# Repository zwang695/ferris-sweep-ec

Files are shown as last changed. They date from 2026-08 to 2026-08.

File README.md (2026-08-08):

# Ferris Sweep EC

An open, 34-key (`3x5+2` per half) Topre electrocapacitive split keyboard using
Ferris Sweep-style geometry and the known-built Tako Rev1 sensing architecture.

## Tooling

KiCad 10.0.5 is installed through Flatpak. Use `./scripts/kicad-cli` for
schematic ERC, PCB DRC, exports, and renders. QMK CLI 1.2.0 is also available;
firmware is kept reproducible in this repository rather than depending on the
machine's existing QMK checkout.

This repository is an engineering project. Files under `production/` are not
released for fabrication until every check in `docs/verification-plan.md` has
passed and the release is explicitly tagged as a prototype.

## Revision A goals

- Functional wired electrocapacitive keyboard.
- Separate, non-reversible left and right PCBs.
- 19.05 mm nominal key pitch with Sweep-style column stagger.
- 17 keys per half: three rows of five plus two thumb keys.
- Socketable Pro-Micro-pin-compatible RP2040 controller and local EC sensing
  front end on each half.
- QMK firmware with raw ADC diagnostics for post-assembly threshold tuning.
- USB-C on both halves for flashing and independent bring-up.
- Wired serial split transport.
- No RGB, display, encoder, wireless, or Vial in Revision A.

## Repository layout

- `docs/` — requirements, decisions, reference audit, and verification plan.
- `hardware/` — KiCad project and project-local libraries.
- `mechanical/` — layout coordinates, plate, and compression-stack files.
- `firmware/` — QMK keyboard implementation and keymaps.
- `simulation/` — analog-front-end models and ADC stimulus traces.
- `tests/` — schematic, PCB, firmware, and generated-output checks.
- `references/` — pinned upstream metadata; third-party files retain their
  original licenses and are not copied here until their provenance is clear.
- `production/` — generated Gerbers, drills, BOM, and placement files.

## Status

Controller PCB, Topre plate, bottom plate, and upstream-QMK firmware now pass
the automated pre-fabrication checks. The project remains a prototype: static
checks and behavioral models cannot replace calibration with real domes,
springs, housings, and fabricated sensor electrodes.

Run `./scripts/check-all` for the complete automated gate. See
`docs/tooling.md`, `docs/verification-status.md`, `docs/bom.md`, and
`docs/bring-up.md` for setup, evidence, parts, and physical validation. The
Tako/Cipulot comparison is in `docs/ec-cross-check.md`.

For the wired JLCPCB fabrication and assembly package, run
`./scripts/generate-jlcpcb` and follow `production/jlcpcb/README.md`.

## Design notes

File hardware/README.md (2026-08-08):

# Hardware

`rev-a/` contains the active KiCad 10 design. It starts as a mechanically
imported, renamed copy of the pinned MIT-licensed Tako Rev1 source. The import
is reproducible with `scripts/import-tako-rev1`; subsequent changes are made in
the active source and reviewed against the imported baseline.

The upstream project commit and all other references are pinned in
`references/reference-audit.md`. The original MIT text is retained as
`hardware/LICENSE.tako.MIT`.

The project-level ERC, DRC, firmware, and mechanical gates in
`docs/verification-plan.md` now pass. Revision A is suitable for an informed
prototype review; physical Topre signal margin remains unproven until a real
dome, spring, housing, and fabricated sensor stack are measured.

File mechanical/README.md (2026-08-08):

# Mechanical

This directory will contain canonical key coordinates, PCB outline sources,
the Topre/OEM plate, and stack drawings. Sweep geometry is a layout input; EC
housing cutouts and compression dimensions come from the proven reference and
selected Topre-compatible physical parts.

Revision A uses a 1.2 mm nominal plate. NiZ compatibility and its separate
plate stack are out of scope.

The active plate is in `topre-plate/`. One plate file represents one half;
fabrication requires two copies, with one flipped for the opposite hand. Its
housing cutouts, mounting holes, and key coordinates are retained from the
known-built Tako Rev1 Topre/OEM plate.

The matching lower enclosure PCB is in `bottom-plate/`. It is likewise a
single-half file to be fabricated twice. Its controller, display, TRRS, and
mounting cutouts follow the same pinned Tako Rev1 mechanical stack.

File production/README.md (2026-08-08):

# Production outputs

Do not fabricate files merely because they appear here. A manufacturing package
is releasable only after all gates in `docs/verification-plan.md` pass and its
directory is explicitly marked as a prototype release.

`fabrication-notes.md` records the intended order quantities, thicknesses, and
the CAM features that must not be automatically altered.

`jlcpcb/` contains the reviewed wired-only part map and exact order procedure.
Run `scripts/generate-jlcpcb` for upload-ready controller PCBA and plate ZIPs.

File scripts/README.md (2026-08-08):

# Project scripts

- `kicad-cli` runs KiCad 10 through Flatpak.
- `check-hardware` runs ERC, three DRCs, parity, and netlist assertions.
- `check-models` runs mapping and ADC-classifier behavioral tests.
- `check-firmware` lints and builds default/diagnostic UF2s on pinned upstream
  QMK.
- `generate-production` regenerates Gerbers, drills, BOM, placement, renders,
  and checksums.
- `generate-jlcpcb` creates the filtered wired-only JLCPCB PCBA/plate upload
  package, assembly drawings, and checksums.
- `check-all` runs the complete automated pre-fabrication gate.

The `import-tako-*` scripts are provenance-preserving baseline importers, not
normal build steps. They refuse to overwrite the active Revision A sources.

Examples:

```sh
./scripts/kicad-cli version
./scripts/check-all
./scripts/generate-jlcpcb
```

The Flatpak sandbox may request permission to access the project directory.

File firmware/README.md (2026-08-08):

# Firmware

The active QMK keyboard overlay is in `qmk/keyboards/ferris_sweep_ec`. It uses
the proven Tako split EC scan sequence and retains raw ADC console output for
bench validation.

Revision A targets a Pro-Micro-pin-compatible RP2040 module through QMK's
`rp2040_ce` converter. An ATmega32U4 Pro Micro is not supported: its ADC,
memory, and timing are not suitable for this design.

Revision A runs on regular upstream QMK with the Tako custom EC scanner adapted
to a split `4x5` logical matrix per half. No QMK core fork is required.

The default keymap remains intentionally minimal. The diagnostic keymap emits
raw ADC readings through QMK Console so the fixed per-key press and release
thresholds can be tuned after assembly. It does not claim automatic
calibration.

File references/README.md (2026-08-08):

# Reference policy

Third-party design files are admitted only after their source, revision, hash,
and license are recorded in `reference-audit.md`. The original Cipulot EC60 and
CorneECRevival GitHub URLs were unavailable during project initialization, so
unidentified mirrors must not silently become design authority.

Expected references:

- Ferris Sweep: physical key coordinates and ergonomic outline only.
- Corne EC Revival: split EC topology and mechanical variants.
- EC60: sensor, analog front end, STM32, USB, and calibration implementation.
- Another Cipulot EC board: independent cross-check of repeated circuitry.
- Current QMK `keyboards/cipulot/common`: firmware behavior and configuration
  contract.
- ST and analog-multiplexer manufacturer documentation: pin and electrical
  validation.

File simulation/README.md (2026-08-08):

# Simulation

Synthetic ADC classifier coverage lives in `tests/test_adc_classifier.py`.
It exercises the exact 650/700 hysteresis contract without pretending to know
the physical sensor capacitance.

An absolute analog model is deliberately deferred until a selected dome,
spring, housing, PCB finish, and assembled stack provide measured released and
bottomed-out readings. Without those boundary conditions, a capacitance sweep
would create precise-looking but unvalidated signal margins.

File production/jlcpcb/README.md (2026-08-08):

# JLCPCB wired prototype package

Run `./scripts/generate-jlcpcb` to create the upload-ready files under
`production/generated/jlcpcb/`. The package is for the wired Revision A only.
It does not populate controllers, controller sockets, optional feedback
jumpers, display/wireless parts, battery parts, sensor electrodes, or mounting
holes.

## Upload files

Create three JLCPCB orders:

| Order | Upload | Service |
|---|---|---|
| Controller/sensor panel | `controller-gerbers.zip`, then `controller-bom.csv` and `controller-cpl.csv` | Standard PCBA, both sides, mixed SMT/THT |
| Topre plate | `topre-plate-gerbers.zip` | PCB only |
| Bottom plate | `bottom-plate-gerbers.zip` | PCB only |

The controller Gerber is already a complete customer panel containing one left
and one right PCB. Declare **two different designs**, do not ask JLCPCB to
panelize it again, and choose **Complete file / proceed with my own files** when
the assembly uploader asks how to interpret panel placement data.

## Controller order settings

- FR-4, 2 layers, 230.7946 x 97.8403 mm as detected from the Gerbers.
- 1.6 mm finished thickness, 1 oz copper.
- ENIG surface finish; default ENIG gold thickness is acceptable.
- Customer panel, two different designs, mouse-bite separation.
- Standard PCBA, assemble both top and bottom sides.
- Select the lowest prototype PCB quantity offered and assemble at least two
  panels if required by the service minimum.
- Remove the JLCPCB order number. Do not permit an order number, label, or
  silkscreen addition over any exposed EC sensor electrode.
- Select Confirm Production File if offered.
- Do not order a separate stencil unless you personally want one; PCBA includes
  the production stencil process.

At BOM review, all 38 designators must match. Do not substitute a different
package for any part. Stock can change, so confirm each MPN, JLCPCB part number,
package, and quantity in the order UI.

## Plate orders

Topre plate:

- FR-4, 2 layers, 111.7465 x 97.8403 mm.
- **1.2 mm** finished thickness, 1 oz copper, ENIG.
- One design; order the minimum quantity offered. Two identical boards are
  needed per keyboard and one is flipped for the opposite hand.

Bottom plate:

- FR-4, 2 layers, 114.0803 x 97.8403 mm.
- 1.6 mm finished thickness, 1 oz copper, ENIG.
- One design; order the minimum quantity offered. Two identical boards are
  needed per keyboard and one is flipped for the opposite hand.

For both plate orders, preserve all routed internal cutouts, plated rings, and
separate PTH/NPTH drill files. Reject CAM requests to close or move them.

## Required placement review

JLCPCB requires the customer to confirm rotations in its placement viewer.
Compare it with `controller-assembly-top.pdf` and
`controller-assembly-bottom.pdf` before paying. In particular:

- `U2`: 90 degrees; `U102`: 270 degrees.
- `U3`: 0 degrees; `U103`: 180 degrees.
- The pin-1 indicator for every IC must agree with the PDF and PCB copper.
- `J1` and `J101` must face outward toward their matching board edges.
- `RSW1` and `RSW101` must sit flat inside their outlines.

Stop and correct the CPL rather than approving a visibly rotated IC or jack.

## Intentionally not installed by JLCPCB

- `U1`, `U101`: socketable RP2040 CE controllers.
- `JP1`, `JP101`: optional op-amp feedback/gain resistors.
- `DISP1`, `DISP101`, `PSW1`, `PSW101`, and all `BAT_HOLE*` references.
- `SW1` through `SW17` and `SW101` through `SW117`: these are bare EC sensor
  electrodes, not switches to purchase.
- All `H*` references: mechanical holes, not components.

The controller footprints provide two 12-pin, 2.54 mm rows per half. After
PCBA, install four 1x12 female socket strips on the keyboard and matching male
pins on the two controllers, or ask a local electronics technician to do it.
The normal JLCPCB upload package deliberately does not pretend those two
separate socket strips are a single placeable `U1` component.

Finally, connect or disconnect TRRS only while both halves are unpowered.

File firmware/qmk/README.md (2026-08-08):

# QMK firmware overlay

`keyboards/ferris_sweep_ec` is the project-owned QMK keyboard directory. It is
derived from the GPL-licensed ssbb Tako firmware pinned in the reference audit,
then ported to the current upstream QMK APIs. Original copyright and license
headers are preserved in each source file. The ssbb fork is a provenance and
regression reference, not a final build dependency.

The initial compile target is:

```sh
qmk compile -kb ferris_sweep_ec/rev_a -km default -e CONVERT_TO=rp2040_ce
```

The firmware remains diagnostic-first: console output exposes raw EC readings
so thresholds can be checked and calibrated once physical hardware exists.
The `diagnostic` keymap provides a plain one-layer position map and builds as a
separate UF2; the custom matrix prints the same raw readings in both builds.

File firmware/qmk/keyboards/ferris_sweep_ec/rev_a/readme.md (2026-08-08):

# Ferris Sweep EC Revision A

Revision A is a 34-key split electrocapacitive keyboard derived from the
MIT-licensed ssbb Tako Rev1 hardware. It targets a Pro-Micro-pin-compatible
RP2040 module and uses a custom QMK matrix scanner for its OPA350/74HC4051 EC
front end.

Build from an upstream QMK checkout with this keyboard directory installed:

```sh
qmk compile -kb ferris_sweep_ec/rev_a -km default -e CONVERT_TO=rp2040_ce
```

Do not substitute an ATmega32U4 Pro Micro. Enable the QMK console during
bring-up to inspect raw sensor values and tune thresholds.

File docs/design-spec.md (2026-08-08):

# Revision A design specification

Status: draft, defaults accepted on 2026-08-08.

## Product definition

Revision A is a wired, split, 34-key electrocapacitive keyboard. Its physical
layout follows the Ferris Sweep family. Its sensing cell and analog front end
are based on the manufactured Tako Rev1 design and cross-checked against
Cipulot's current QMK EC implementations.

The term "Sweep-style" describes the key arrangement and silhouette. It does
not imply Choc spacing, a reversible PCB, a Pro Micro footprint, or a diode
switch matrix.

## Layout

- Two halves, 17 keys per half.
- Main matrix per half: 3 rows x 5 columns.
- Thumb cluster per half: 2 keys.
- Logical EC matrix per half: 4 rows x 5 columns, with three unused cells.
- Nominal center-to-center pitch: 19.05 mm unless physical EC parts require a
  different measured value.
- Separate left and right PCB outlines; no reversible sensor PCB.

## Electrical architecture

- One socketable, Pro-Micro-pin-compatible RP2040 module per half. AVR Pro
  Micros are electrically pin-compatible but are explicitly unsupported.
- One local EC analog front end per half.
- One 74HC4051 analog multiplexer and one OPA350 peak-hold stage per half.
- USB connection through the replaceable controller module on both halves.
- Reset, power, ADC, mux, row-drive, and split-transport test pads.
- QMK-supported RP2040 serial transport between halves.
- PJ-320A TRRS carries serial, 3.3 V, and ground as in the proven reference.
  It is not hot-plug safe; connect or disconnect it only with USB removed.

## Mechanical architecture

- Topre-compatible plate-mounted housings with conical springs and individual
  domes. NiZ compatibility is explicitly out of scope for Revision A.
- One Topre/OEM plate variant at 1.2 mm nominal thickness, matching the proven
  reference stack. Preserve its cutouts and housing orientation until measured
  parts justify a change.
- PCB, plate, and case must form a controlled compression stack; a bare PCB is
  not considered a functional keyboard assembly.
- Final plate cutouts and stack heights require measurements or authoritative
  drawings for the selected physical parts.

## Explicit non-goals for Revision A

- Wireless or batteries.
- Per-key or underglow lighting.
- Displays, encoders, pointing devices, or haptics.
- Hot-swap mechanical switches.
- Vial dynamic configuration before basic QMK sensing is stable.
- Commercial distribution.
- NiZ housings, sliders, domes, or plate compatibility.

The inherited display, battery-contact, and battery-switch footprints remain
in the frozen known-built geometry but are explicitly marked DNP. They are not
part of the Revision A BOM or firmware feature set.

## Change-control rule

The following proven EC elements may not be changed without an explicit design
decision and new verification evidence:

- sensor electrode geometry;
- copper and soldermask exclusions around the sensor;
- analog peak-hold and discharge topology;
- analog component values and device types;
- row excitation polarity and timing;
- ADC reference/supply arrangement;
- QMK raw-sample and calibration sequence;
- relevant PCB layer construction beneath the sensor.

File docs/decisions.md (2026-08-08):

# Design decision log

## D-001: 34-key layout

- Decision: `3x5+2` per half.
- Reason: user requested Ferris Sweep style.
- Status: accepted.

## D-002: proven EC architecture

- Decision: derive sensing hardware from Cipulot EC references and current QMK
  EC code instead of designing a new capacitive-sensing method.
- Reason: minimize first-revision electrical risk.
- Status: accepted.

## D-003: controller family

- Decision: use a socketable Pro-Micro-pin-compatible RP2040 module for
  Revision A; do not fit an ATmega32U4 Pro Micro.
- Reason: the manufactured and supported Tako Rev1 uses this arrangement. Its
  author explicitly warns against building the integrated-STM32 Rev0. A
  replaceable module removes USB, crystal, regulator, boot, and fine-pitch MCU
  assembly from the first custom PCB while retaining a QMK-capable ADC.
- Status: accepted from reference evidence; revisit an integrated STM32 only
  after a working Revision A exists.

## D-004: separate PCBs

- Decision: separate, non-reversible left and right sensor PCBs.
- Reason: avoid compromises in sensor-side copper, analog routing, and assembly.
- Status: accepted.

## D-005: primary electrical reference

- Decision: use `ssbb/tako` Rev1 as the primary hardware reference and use
  current `qmk/qmk_firmware` Cipulot EC boards plus the ssbb Tako QMK fork as
  independent firmware/topology cross-checks.
- Reason: Tako Rev1 is MIT-licensed, 34-key, split, built in hardware, and
  explicitly credits Cipulot. It already uses a 4x5 logical matrix per half,
  OPA350 peak hold, and one 74HC4051 per half.
- Status: accepted.

## D-006: do not inherit reference violations

- Decision: recreate/clean the project in KiCad 10 and require clean ERC and
  DRC instead of declaring the imported reference reports acceptable.
- Reason: KiCad 10 reports six ERC errors and nine DRC errors on the untouched
  Tako Rev1 source, alongside warnings caused by missing/renamed libraries.
  The source has no unconnected PCB items, but its reports are not a release
  baseline for this project.
- Status: accepted.

## D-007: upstream QMK is the build target

- Decision: compile Revision A against a pinned commit of the regular
  `qmk/qmk_firmware` repository. Keep `ssbb/qmk_firmware` only as the
  known-working Tako reference.
- Reason: EC needs a custom analog matrix scanner, but it does not require QMK
  core changes. The local keyboard driver was ported to current GPIO,
  split-hand, metadata, and keycode APIs; it compiles to RP2040 UF2 and passes
  `qmk lint` on upstream commit
  `9caa5f871ddb9813c7370708be62d7a3e1cfeb75`.
- Status: accepted and build-verified.

## D-008: Topre-only mechanical stack

- Decision: Revision A supports Topre-compatible/OEM-style EC parts only. Use
  the reference 1.2 mm plate stack and do not create a NiZ plate variant.
- Reason: user selected Topre and explicitly removed the NiZ requirement;
  maintaining one proven stack reduces mechanical and sensing uncertainty.
- Status: accepted.

## D-009: retain the proven wired split link

- Decision: retain Tako Rev1's PJ-320A TRRS serial/power link for Revision A.
- Reason: replacing it would change a proven routed connector, bottom-plate
  cutout, power path, and firmware transport. It must never be hot-plugged.
- Status: accepted for the prototype; a keyed connector is a future revision.

## D-010: RP2040 Community Edition controller contract

- Decision: lock firmware and pins to QMK's `rp2040_ce` Pro Micro converter,
  while allowing any mechanically compatible controller implementing that
  pinout.
- Reason: this preserves GPIO 27 as the F6 ADC input, VBUS detection for split
  use, and the known-working physical module footprint without depending on a
  single small vendor's stock.
- Status: accepted and compile-verified.

## D-011: copied two-layer stack

- Decision: use two-layer, 35 um copper FR-4: 1.6 mm for the sensor PCB and
  bottom plate, and 1.2 mm for the Topre plate.
- Reason: these are the known-built Tako Rev1 stack values; the 1.2 mm housing
  plate is mechanically critical.
- Status: accepted and recorded in fabrication notes.

## Open decisions

- Exact Topre-compatible dome weight, spring, housing, and MX-compatible
  slider vendor.
- Exact RP2040 CE controller vendor/model for the first parts order.

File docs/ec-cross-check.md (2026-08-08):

# EC architecture cross-check

The active design is a cleaned Tako Rev1 derivative because Tako already is a
built, 34-key, split, Sweep-like EC keyboard. Re-laying it out from the older
Corne EC would add risk without changing the target. The original Cipulot
Corne EC repository could not be recovered from an authoritative upstream
location, so no file in this project is represented as a direct Corne copy.

## Hardware contract retained from Tako Rev1

- one 74HC4051 analog mux per half for five physical columns;
- four driven row buses per half, with three unused logical cells;
- paired EC electrode geometry copied without modification;
- OPA350 stage, 220 pF hold capacitor, 1 kohm isolation/feedback network, and
  10 us firmware discharge interval;
- local 3.3 V sensing power controlled by the controller;
- separate left/right nets and sensor routing;
- RP2040 CE module, GPIO 27 ADC input, and serial split link.

The XML netlist test checks those relationships independently of PCB net names,
and the mux-channel test ties the schematic's 4051 input pins to the exact QMK
channel arrays.

## Current Cipulot QMK comparison

| Behavior | Cipulot EC60 / common driver | EC23U / EC60X | Revision A |
|---|---|---|---|
| Scan sequence | select mux, pulse row, ADC read, discharge | same | same inherited sequence |
| Discharge | 10 us | 10 us | 10 us |
| ADC scale | 10-bit thresholds | 10-bit thresholds | 10-bit thresholds |
| Mux topology | two 8-channel muxes for 15 columns | one mux for 6 or 15 columns | one 8-channel mux for 5 columns per half |
| Press/release | separate thresholds | separate thresholds | fixed 700/650 hysteresis |
| Calibration | sampled noise floor and bottom-out scaling | same current common driver | raw console capture and manual per-build calibration |
| Rapid trigger | supported | supported | deliberately out of scope |
| Split support | not required by EC60 | board dependent | known-working Tako split mapping retained |

The modern Cipulot driver is stronger for per-key calibration and rapid
trigger. Porting all of it would be a firmware feature project, not a
requirement for first electrical function. Revision A keeps the smaller
known-working Tako scanner, exposes raw readings, and requires measured
threshold calibration during bring-up.

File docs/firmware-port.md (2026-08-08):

# Upstream QMK port

Revision A builds on regular upstream QMK. No QMK core fork is required.

## Why the ssbb fork is still recorded

Tako's keyboard directory was not merged into upstream QMK, so the ssbb fork
is the authoritative source for its known-working RP2040 EC scan sequence,
split-hand pin mapping, and thresholds. Pinning it makes that provenance
reproducible; it does not make it a runtime or build dependency.

## Local changes for current upstream QMK

- migrated legacy `setPin*`/`writePin*` calls to current `gpio_*` APIs;
- migrated the split-side global `isLeftHand` to `is_keyboard_left()`;
- adopted `keyboard.json` as the leaf build marker;
- moved conditional make logic into `post_rules.mk`;
- updated retired mouse keycode aliases;
- retained the keyboard-local ADC and custom matrix implementation.

## Verified baseline

- Upstream: `qmk/qmk_firmware`
- Commit: `9caa5f871ddb9813c7370708be62d7a3e1cfeb75`
- Target: `ferris_sweep_ec/rev_a:default`
- Converter: `rp2040_ce`
- Result: UF2 linked successfully and `qmk lint` passed on 2026-08-08.

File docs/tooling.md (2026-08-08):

# Tooling and repeatable commands

No PCB-design experience is required to run or inspect the current checks.
Editing the design still benefits from learning KiCad's schematic and PCB
editors, but the release gates are command-line driven.

## Software

- Git, Python 3, GNU Make, and `rsync`.
- KiCad 10.0.x. This workspace uses the official Flatpak package so the GUI
  and `kicad-cli` stay on the same version.
- QMK CLI plus the ARM GNU toolchain. `qmk setup` installs/checks the normal
  QMK development prerequisites for your OS.
- A text editor. No third-party Python packages are required by this project.

On a Linux system with Flatpak:

```sh
flatpak install flathub org.kicad.KiCad
python3 -m pip install --user qmk
qmk setup
```

The project wrapper is `./scripts/kicad-cli`; KiCad also ships a real CLI, but
the wrapper selects the Flatpak installation used for this baseline.

## Main commands

```sh
./scripts/check-hardware
./scripts/check-models
./scripts/check-firmware
./scripts/generate-production
./scripts/check-all
```

`check-all` is the normal command. It writes ignored reports and fabrication
artifacts under `production/generated/`. The committed design sources remain
under `hardware/`, `mechanical/`, and `firmware/`.

## What I can help change

I can modify and verify the schematic, PCB, custom design rules, footprints,
plate files, QMK scanner/keymaps, tests, BOM, Gerbers, and documentation. I can
also analyze ADC logs after assembly and derive per-key thresholds. Your
unavoidable interventions are choosing/buying the physical Topre parts,
ordering and assembling the boards, taking measurements, and connecting real
hardware for final calibration.

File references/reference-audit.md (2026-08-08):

# Reference audit

Status: primary sources pinned; available authoritative sources cross-checked.

| Reference | Intended use | Revision/hash | License | Retrieved | Notes |
|---|---|---|---|---|---|
| Ferris Sweep | key stagger and silhouette | `davidphilipbarr/Sweep@8ba72a256d627567660ecc0b6f51bb18fa8badb5` | Solderpad Hardware License 2.1 / Apache-2.0 option | 2026-08-08 | Sweep Mini is the coordinate reference; EC pitch remains 19.05 mm |
| Tako Rev1 | primary 34-key EC hardware | `ssbb/tako@5aa952ab5d5dc0c83aef36756252b27efc64e4cd` | MIT | 2026-08-08 | Manufactured design; OPA350, 74HC4051, controller module; only its Topre/OEM stack is in scope |
| Tako Rev0 | negative/control reference | same commit as Tako Rev1 | MIT | 2026-08-08 | Integrated STM32F4x1; author explicitly warns not to build it |
| Corne EC Revival | historical split EC architecture | unavailable | not yet independently recovered | no | original Cipulot repository URL currently returns not found; do not copy from unattributed mirrors |
| Cipulot EC60 | current electrical/firmware cross-check | `qmk/qmk_firmware@9caa5f871ddb9813c7370708be62d7a3e1cfeb75`, `keyboards/cipulot/ec_60` | GPL-2.0-or-later headers in firmware | 2026-08-08 | Current QMK configuration uses two muxes for 15 columns |
| Cipulot EC23U / EC60X | small/single-mux firmware cross-check | same QMK commit | GPL-2.0-or-later headers in firmware | 2026-08-08 | EC23U proves one mux for six columns; EC60X one mux for sixteen columns |
| Upstream QMK | final firmware build environment | `qmk/qmk_firmware@9caa5f871ddb9813c7370708be62d7a3e1cfeb75` | GPL and component licenses | 2026-08-08 | Revision A compiles and lints here; this is the final build target |
| Tako QMK firmware | split firmware provenance/regression reference | `ssbb/qmk_firmware@5d3c06185eee1663503bfd346dc5433c1a48a67a` | GPL-2.0-or-later headers in firmware | 2026-08-08 | Source of the known-working scanner and mapping; not a final build dependency |

## Required subsystem comparison

| Subsystem | Corne EC | EC60 | Additional EC | Revision A decision |
|---|---|---|---|---|
| Sensor electrode | source unavailable | current firmware only | Tako Rev1 EC pad | copy the MIT-licensed Tako Rev1 pad exactly, then verify dimensions |
| Peak hold/discharge | source unavailable | OPA-based interface expected from firmware contract | OPA350, 220 pF hold capacitor, 1 kOhm ADC isolation, MCU-controlled discharge | preserve Tako Rev1 topology and values |
| Analog mux | source unavailable | EC23U uses one mux for six columns | one 74HC4051 per half for five columns | one 74HC4051 per half |
| Row drive | source unavailable | four/five GPIO rows depending board | four GPIO rows per half | four GPIO rows per half |
| MCU/ADC | STM32-era design reported | supported by current ChibiOS code | supported RP2040 module | RP2040 module for replaceability and proven Rev1 path |
| Power/decoupling | source unavailable | board-specific | 3.3 V local rail, 100 nF local bypassing | reproduce and add explicit power flags/test points |
| USB/ESD | source unavailable | board-specific | provided by controller module | controller module owns USB for Revision A |
| Boot/reset/SWD | source unavailable | board-specific | module reset access | reset plus accessible module debug/test pads where possible |
| Split transport/power | historical split | n/a | serial plus power over TRRS | retain the proven TRRS/QMK serial mapping for Revision A; never hot-plug it |
| PCB sensor keepout | source unavailable | not represented in firmware | local copper and soldermask exclusions in EC footprint | copy exactly and test by rule/script |
| QMK configuration | unavailable | current adaptive Cipulot driver | known-working Tako split driver | start from Tako driver, retain raw-value diagnostic build |

The detailed scan-sequence and calibration comparison is recorded in
`docs/ec-cross-check.md`. The unavailable original Corne source remains a
provenance limitation, not a reason to copy an unattributed mirror.

## KiCad 10 baseline on untouched Tako Rev1

- ERC: 144 findings: 6 errors and 138 warnings. Most warnings are missing
  library/link metadata under the clean KiCad 10 environment.
- DRC: 67 findings: 9 errors and 58 warnings, with zero unconnected items.
- These results establish provenance and useful negative tests; they are not a
  waiver. This project's own source must pass with no unexplained findings.

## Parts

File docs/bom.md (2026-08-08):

# Revision A build BOM

This is a wired, Topre-only build. Quantities below are for one complete split
keyboard (both halves). Exact manufacturer parts follow the known-built Tako
Rev1 where one was specified.

| Qty | Part | Package / note |
|---:|---|---|
| 2 | OPA350UA op amp | SOIC-8; TI OPA350 family |
| 2 | 74HC4051D analog mux | SOIC-16, 3.9 x 9.9 mm, 1.27 mm pitch |
| 4 | 100 nF capacitor | 0805, X7R or C0G, at least 6.3 V |
| 2 | 220 pF capacitor | 0805, C0G/NP0 preferred |
| 8 | 100 ohm resistor | 0805, 1% |
| 12 | 100 kohm resistor | 0805, 1% |
| 2 | 1 kohm resistor | 0805, 1% |
| 2 | 5.1 kohm resistor | 0805, 1% |
| 2 | Panasonic EVQPUC02K-compatible reset switch | PCB footprint is Panasonic EVQPUL/EVQPUC |
| 2 | PJ-320A TRRS jack | XKB Connectivity-compatible footprint |
| 2 | RP2040 Community Edition controller | Same model on both halves; USB-C recommended |
| 4 | 1x12 female socket strip | 2.54 mm pitch; two rows per keyboard half |
| 4 | 1x12 male pin strip | 2.54 mm pitch; omit if already installed on controllers |
| 34 | Topre-compatible OEM housings | MX-compatible sliders required by housing orientation |
| 34 | MX-compatible Topre sliders | Match housings and keycaps |
| 34 | Topre domes | Select weight to preference |
| 34 | Conical springs | Match the dome family |
| 34 | Silencing rings, optional | Match slider/housing family |
| 16 | M2 x 6 mm standoffs | Maximum 3.4 mm outside diameter |
| 32 | M2 x 4 mm screws | For the outside plate stack |
| 12 | M1.6 x 6 mm standoffs | Six per half at the inner housing positions |
| 24 | M1.6 x 4 mm screws | For the inner plate stack |

The controller build target is QMK's `rp2040_ce` pinout. Compatible families
listed in the pinned QMK documentation include Liatris, Helios, Elite-Pi,
Frood, Sea-Picro EXT, and Splinky. Do not substitute an ATmega32U4 Pro Micro.
The SparkFun Pro Micro RP2040 uses a separate QMK converter target and is not
the locked Revision A firmware target.

The normal JLCPCB package leaves the controllers and their socket strips for
post-PCBA installation because each controller footprint represents two
physically separate socket rows. Buy controllers with male pins already fitted
or have a local electronics technician solder the sockets and pins.

## Do not populate

- `DISP1`, `DISP101`: display is outside Revision A scope.
- `PSW1`, `PSW101`: wireless/battery power switch.
- `BAT_HOLE+1`, `BAT_HOLE-1`, `BAT_HOLE+101`, `BAT_HOLE-101`: battery contacts.
- `JP1`, `JP101`: optional op-amp feedback/gain resistor; begin unpopulated,
  as in the reference build, and fit only during measured analog debugging.

The generated KiCad BOM excludes the first three groups automatically. The
sensor electrodes and mechanical mounting holes appear in source metadata but
are not purchased electronic components.

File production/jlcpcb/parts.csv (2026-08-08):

Comment | Designator | Footprint | Manufacturer | Manufacturer Part Number | JLCPCB Part # | Assembly Type
100nF 50V X7R 10% | C1,C3,C101,C103 | 0805 | FH | 0805B104K500NT | C38141 | SMT
220pF 50V C0G 5% | C2,C102 | 0805 | FH | 0805CG221J500NT | C1805 | SMT
100 ohm 1% | R1,R2,R3,R4,R101,R102,R103,R104 | 0805 | UNI-ROYAL | 0805W8F1000T5E | C17408 | SMT
100kohm 1% | R5,R6,R7,R8,R9,R10,R105,R106,R107,R108,R109,R110 | 0805 | UNI-ROYAL | 0805W8F1003T5E | C149504 | SMT
1kohm 1% | R11,R111 | 0805 | UNI-ROYAL | 0805W8F1001T5E | C17513 | SMT
5.1kohm 1% | R12,R112 | 0805 | UNI-ROYAL | 0805W8F5101T5E | C27834 | SMT
Reset switch | RSW1,RSW101 | SMD 4.7x4.5mm | Panasonic | EVQPUC02K | C79174 | SMT
8-channel analog mux | U2,U102 | SOIC-16 | Nexperia | 74HC4051D,653 | C9386 | SMT
Rail-to-rail op amp | U3,U103 | SOIC-8 | Texas Instruments | OPA350UA | C2862236 | SMT
3.5mm four-contact jack | J1,J101 | PJ-320A through-hole | SOFNG | PJ-320A | C22355837 | Wave soldering

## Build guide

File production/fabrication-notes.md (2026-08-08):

# Prototype fabrication notes

These settings preserve the pinned Tako Rev1 electrical and mechanical stack.
This is a prototype package, not a production-qualified release.

## Order quantities

| File set | Quantity | Construction |
|---|---:|---|
| `controller/gerbers` | 1 panel | Two routed halves joined by mouse bites |
| `topre-plate/gerbers` | 2 | One plate per half; flip one during assembly |
| `bottom-plate/gerbers` | 2 | One bottom per half; flip one during assembly |

## Stack settings

- Controller/sensor PCB: 2-layer FR-4, 1.6 mm finished thickness, 1 oz / 35 um
  copper, soldermask both sides.
- Topre plate: 2-layer FR-4, **1.2 mm finished thickness**, 1 oz / 35 um
  copper. Do not let the fabricator substitute 1.6 mm.
- Bottom plate: 2-layer FR-4, 1.6 mm finished thickness, 1 oz / 35 um copper.
- ENIG is recommended for flat, oxidation-resistant exposed sensor and plate
  copper. Keep the finish consistent across prototypes because it can affect
  the EC baseline.
- Any normal soldermask color is acceptable; keep it consistent during A/B
  testing.

## Routing and review notes

- Preserve all internal Topre housing routes and the copper/mask rings around
  them. They are intentional; do not apply an automatic copper-to-edge repair.
- Preserve the controller panel mouse bites and route outline.
- Plated and non-plated drill files are separate. Submit both.
- The controller is not reversible. The panel contains distinct left and right
  halves; do not mirror either Gerber set.
- The Topre and bottom files each describe one half. Two identical fabricated
  copies are used, with one physically flipped for the opposite hand.
- Request an engineering question from the fab rather than accepting any CAM
  edit to sensor electrodes, cutouts, mounting holes, or panel tabs.

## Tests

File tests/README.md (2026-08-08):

# Tests

`verify-netlist.py` asserts MCU, mux, sensing-cell, peak-hold, ADC, power, and
split-link connectivity from KiCad's generated XML netlist.

The standard-library unit tests assert the 34-key matrix contract, mux channel
order, legal RP2040 ADC mapping, threshold dimensions, hysteresis, drift,
rapid taps, and simultaneous-key classification. Run them with
`../scripts/check-models`.

Tests will include:

- KiCad ERC and DRC jobs;
- critical-net and pin-map assertions;
- sensor-keepout assertions;
- QMK lint and compilation;
- matrix-layout assertions;
- generated ADC trace tests;
- deterministic manufacturing-output generation.

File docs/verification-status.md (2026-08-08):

# Revision A verification status

Last automated run: 2026-08-08 with KiCad 10.0.5 and upstream QMK commit
`9caa5f871ddb9813c7370708be62d7a3e1cfeb75`.

| Gate | Status | Evidence |
|---|---|---|
| Provenance | Pass | Pinned Sweep, Tako, upstream QMK, and ssbb QMK revisions; copied hardware retains MIT notice and firmware GPL headers |
| Schematic | Pass with reviewed warnings | Zero ERC errors; eight exact warnings are allowlisted for intentional aliases, firmware-switched power, and frozen symbols |
| Controller PCB | Pass | Zero DRC violations and zero unconnected items |
| Topre plate | Pass | Zero DRC violations and zero unconnected items under scoped plated-cutout rules |
| Bottom plate | Pass | Zero DRC violations and zero unconnected items under scoped mounting-barrel rules |
| Netlist contract | Pass | 34 sensors, eight row buses, ten mux routes, ADC, peak hold, power, and split nets asserted |
| Firmware | Pass | Default and diagnostic keymaps lint and compile to RP2040 CE UF2 on regular upstream QMK |
| Behavioral model | Pass | Mapping, threshold dimensions, hysteresis, drift, rapid taps, and simultaneous-key tests |
| Manufacturing output | Pass | Gerbers, separate PTH/NPTH drills, BOM, placement CSV, renders, UF2s, and checksums regenerate and pass structure checks |
| JLCPCB wired package | Pass | Filtered 38-placement BOM/CPL, top and bottom paste, mixed-assembly Gerbers, plate ZIPs, assembly drawings, and portable checksums |
| Absolute EC analog margin | Pending physical data | Real dome/spring capacitance and assembled parasitics are not available before fabrication |
| Physical keyboard | Pending fabrication | Requires assembly, ADC capture, threshold calibration, and functional testing |

The project is therefore **ready for informed prototype review**, not proven
production hardware. The generated package is intentionally ignored by Git so
it is always rebuilt from source.

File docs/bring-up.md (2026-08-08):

# Bring-up and end-to-end verification

## What can be proven before ordering

Run `./scripts/check-all`. It verifies KiCad ERC/DRC, PCB-to-schematic
electrical parity, explicit netlist contracts, all 34 matrix positions, mux
channel mapping, ADC pin legality, threshold behavior, current upstream QMK
lint/compile, Gerber/drill generation, and output-file structure.

Open the generated Gerbers in KiCad Gerber Viewer for the independent visual
check:

```sh
flatpak run org.kicad.KiCad
```

Use **File -> Open Gerber Plot File(s)** and load each directory under
`production/generated/*/gerbers`. Check the outline, all internal routes,
sensor-pad exposure, plate copper rings, mouse bites, and left/right labels.

These checks cannot prove the absolute ADC signal produced by a real conical
spring and dome. Capacitance depends on the actual parts, alignment,
compression, PCB dielectric, finish, contamination, and tolerances. A SPICE or
synthetic-trace test can validate the electronics and classifier assumptions,
but it cannot replace one fabricated sensor stack.

## First power-up

1. Break the controller panel into its two halves and inspect the routed edges.
2. With controllers absent, check resistance from each 3.3 V rail to its local
   ground; investigate a near-short before applying power.
3. Inspect OPA350 and 74HC4051 orientation and solder joints.
4. Socket one RP2040 CE controller on one half. Do not connect the TRRS cable.
5. Flash `production/generated/firmware/ferris_sweep_ec_rev_a_diagnostic_rp2040_ce.uf2`
   by entering the controller's UF2 bootloader and copying the file to its
   mounted drive.
6. Open QMK Console. Confirm all 20 logical ADC cells print; the three unused
   positions are ignored by the physical layout.
7. Touch each bare EC electrode. Its reading should rise independently; a
   neighbor rising similarly suggests a mux, row, contamination, or soldering
   fault.
8. Repeat independently on the other half.
9. Power down both halves, connect TRRS, then connect USB. Never insert or
   remove TRRS while USB power is present.
10. Verify all 34 logical positions with a keyboard tester before assembling
    the Topre stack.

## After installing housings, domes, and springs

Record at least 100 released samples and 100 fully pressed samples per key.
For every key, require released readings below the release threshold (650),
pressed readings above the actuation threshold (700), and comfortable margin
beyond both thresholds. If baselines cluster far from the inherited values,
calibrate thresholds from the measured distributions instead of guessing.

Check slow presses, rapid taps, all-key rollover, adjacent-key crosstalk,
split reconnect, USB reconnect, suspend/resume, and at least one extended idle
run. A single key with an unusually high released reading is most often a
misaligned spring/dome stack and should be mechanically inspected first.

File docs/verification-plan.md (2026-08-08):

# Verification plan

No individual check proves an EC keyboard. Release requires static electrical,
PCB, firmware, analog-model, mechanical, and generated-output evidence.

## Reference gate

- Pin every reference to a repository URL and commit or archived artifact hash.
- Record the license for every copied schematic, footprint, PCB, and source file.
- Compare EC Corne, EC60, and at least one other Cipulot EC implementation by
  subsystem.
- Resolve every intentional difference in the decision log.

## Schematic gate

- KiCad ERC has no unexplained errors or warnings.
- Controller-module symbol pin numbers match the RP2040 CE converter and
  physical Pro Micro footprint.
- Power, reset, ADC, mux, rows, and split nets pass scripted
  connectivity assertions.
- Decoupling and analog component values match the selected reference.

## PCB gate

- KiCad DRC has no unexplained errors or warnings.
- Embedded-footprint/library-copy mismatch reporting is disabled. Revision A
  deliberately freezes the geometry from the pinned, known-built Tako source;
  all electrical, clearance, outline, mask, and connectivity checks remain on.
- Sensor electrode and exclusion geometry match the selected reference.
- No unauthorized copper, vias, planes, or footprints occupy sensor keepouts.
- Board outlines, mounting holes, connector openings, and plates pass 1:1 and
  3D mechanical review.
- USB is owned by the socketed controller module; analog routing constraints
  pass on the carrier PCB.

## Firmware gate

- `qmk lint` passes.
- Default and diagnostic keymaps compile.
- Left and right logical matrices contain 17 populated and three unused cells.
- Generated ADC traces test press, release, drift, noise spikes, rapid taps, and
  simultaneous keys.
- Split transport mapping is verified for all 34 key positions.

## Analog-model gate

- The exact firmware hysteresis is tested against synthetic press, release,
  drift, threshold-band noise, rapid-tap, and simultaneous-key traces.
- Absolute sensor-capacitance and parasitic modeling remains pending measured
  physical parts. It cannot be used as pre-fabrication proof of signal margin.
- Press/release separation must be demonstrated with captured per-key ADC
  distributions after assembly.

## Manufacturing-output gate

- Gerbers, drills, netlist, BOM, and placement files regenerate from documented
  commands.
- Gerbers are inspected independently from the KiCad PCB view.
- Fabrication notes specify layer count, thickness, copper, soldermask, finish,
  and any stack details that influence sensing.
- Release is marked `prototype`; no claim of production validation is made.

## Physical validation after fabrication

- Verify shorts and rail resistance before power.
- Bring up and flash each half independently.
- Record raw ADC distributions for every key released and bottomed out.
- Calibrate and test false-press, missed-press, crosstalk, rollover, split-link,
  USB reconnect, suspend/resume, and extended idle behavior.

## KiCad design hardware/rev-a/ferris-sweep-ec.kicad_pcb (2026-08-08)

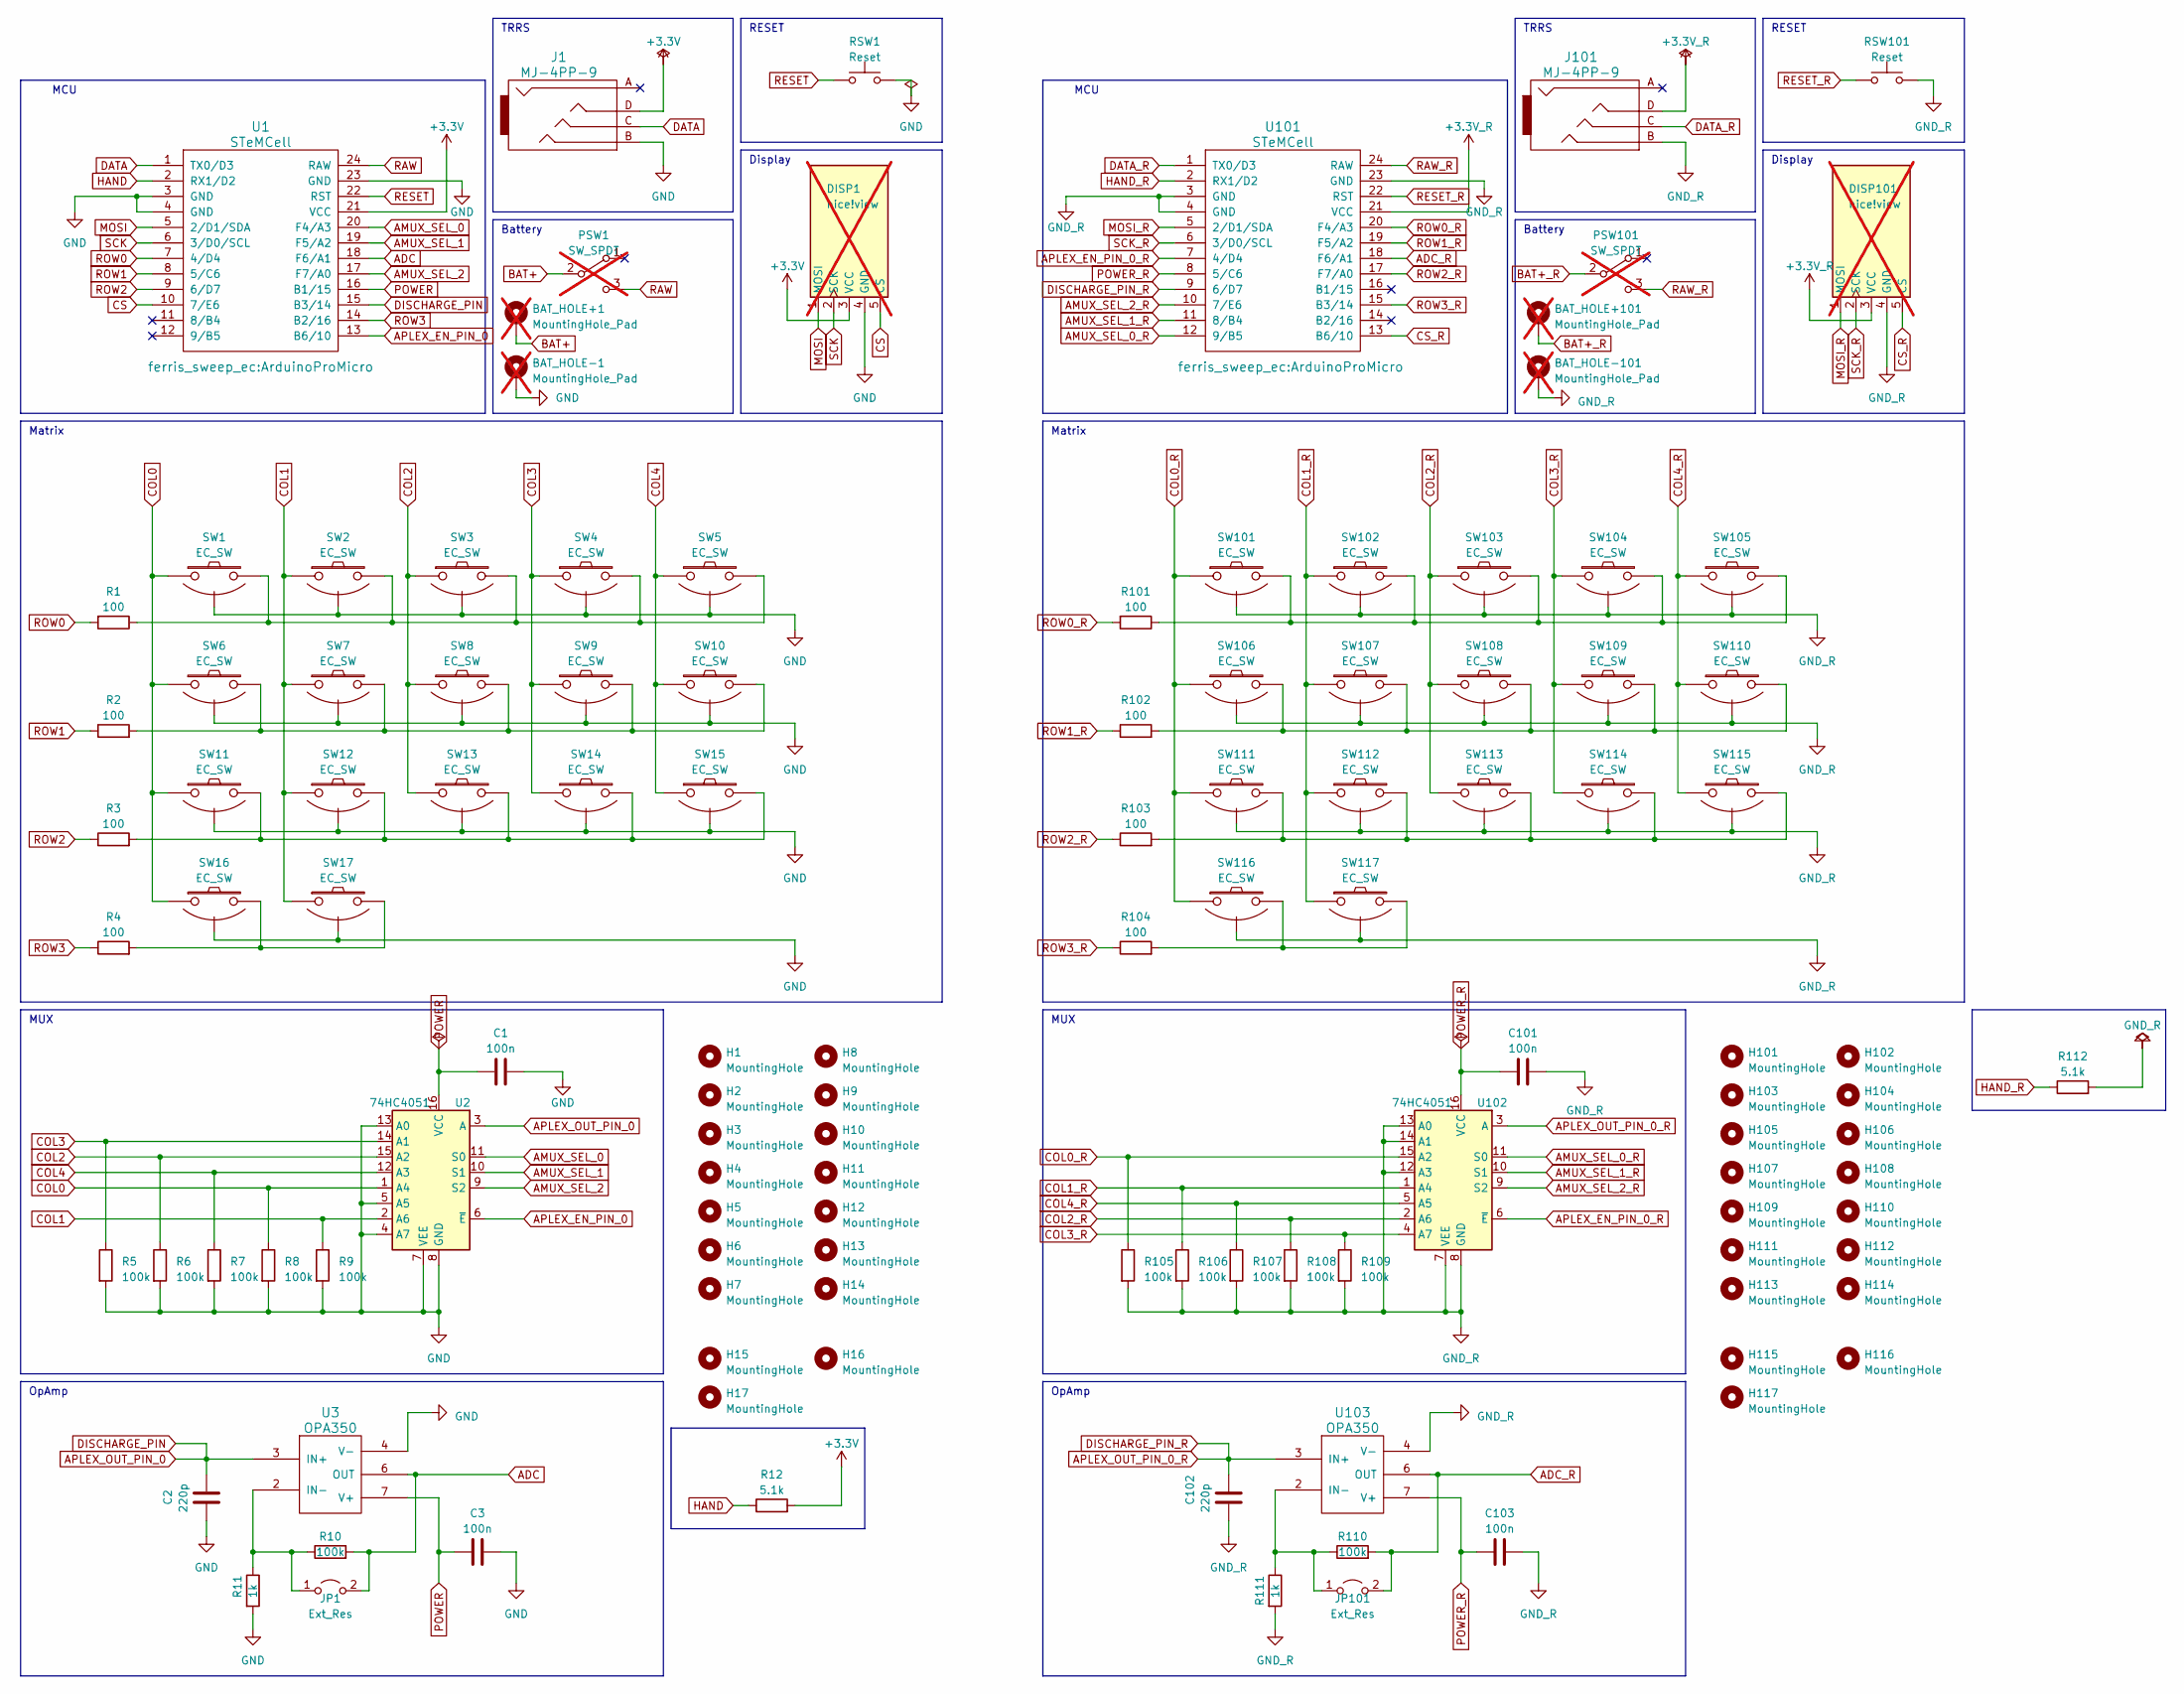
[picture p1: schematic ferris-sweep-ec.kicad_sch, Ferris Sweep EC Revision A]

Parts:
BAT_HOLE+1, BAT_HOLE+101: MountingHole_Pad; bat_pin+; not fitted
BAT_HOLE-1, BAT_HOLE-101: MountingHole_Pad; bat_pin-; not fitted
C1, C3, C101, C103: 100n; C_0805_2012Metric_Pad1.18x1.45mm_HandSolder
C2, C102: 220p; C_0805_2012Metric_Pad1.18x1.45mm_HandSolder
DISP1, DISP101: nice!view; nice_view; not fitted
H1, H2, H3, H4, H5, H6, H7, H8, H9, H10, H11, H12, H13, H14, H101, H102, H103, H104, H105, H106, H107, H108, H109, H110, H111, H112, H113, H114: MountingHole; MountingHole_3.4mm
H15, H16, H17, H115, H116, H117: MountingHole; M2_hole_3.5mm
J1, J101: MJ-4PP-9; TRRS-PJ-320A
JP1, JP101: Ext_Res; R_0805_2012Metric_Pad1.20x1.40mm_HandSolder
PSW1, PSW101: SW_SPDT; SW_SPDT_SMD_PCM12; not fitted
R1, R2, R3, R4, R101, R102, R103, R104: 100; R_0805_2012Metric_Pad1.20x1.40mm_HandSolder
R5, R6, R7, R8, R9, R10, R105, R106, R107, R108, R109, R110: 100k; R_0805_2012Metric_Pad1.20x1.40mm_HandSolder
R11, R111: 1k; R_0805_2012Metric_Pad1.20x1.40mm_HandSolder
R12, R112: 5.1k; R_0805_2012Metric_Pad1.20x1.40mm_HandSolder
RSW1, RSW101: Reset; Panasonic_EVQPUL_EVQPUC
SW1, SW2, SW3, SW4, SW5, SW6, SW7, SW8, SW9, SW10, SW11, SW12, SW13, SW14, SW15, SW101, SW102, SW103, SW104, SW105, SW106, SW107, SW108, SW109, SW110, SW111, SW112, SW113, SW114, SW115: EC_SW; ecs_pad_1U_no_ring
SW16, SW17, SW116, SW117: EC_SW; ecs_pad_1U_no_ring_90deg
U1, U101: STeMCell; ArduinoProMicro
U2, U102: 74HC4051; SOIC-16_3.9x9.9mm_P1.27mm
U3, U103: OPA350; SOIC-8_3.9x4.9mm_P1.27mm

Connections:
+3.3V: DISP1.3 (VCC), J1.D, R12.2, U1.21 (VCC)
+3.3V_R: DISP101.3 (VCC), J101.D, U101.21 (VCC)
ADC: JP1.2 (B), R10.2, U1.18 (F6/A1), U3.6 (OUT)
ADC_R: JP101.2 (B), R110.2, U101.18 (F6/A1), U103.6 (OUT)
AMUX_SEL_0: U1.20 (F4/A3), U2.11 (S0)
AMUX_SEL_0_R: U101.12 (9/B5), U102.11 (S0)
AMUX_SEL_1: U1.19 (F5/A2), U2.10 (S1)
AMUX_SEL_1_R: U101.11 (8/B4), U102.10 (S1)
AMUX_SEL_2: U1.17 (F7/A0), U2.9 (S2)
AMUX_SEL_2_R: U101.10 (7/E6), U102.9 (S2)
APLEX_EN_PIN_0: U1.13 (B6/10), U2.6 (~E)
APLEX_EN_PIN_0_R: U101.7 (4/D4), U102.6 (~E)
APLEX_OUT_PIN_0: C2.1, U1.15 (B3/14), U2.3 (A), U3.3 (IN+)
APLEX_OUT_PIN_0_R: C102.1, U101.9 (6/D7), U102.3 (A), U103.3 (IN+)
BAT+: BAT_HOLE+1.1, PSW1.2 (B)
BAT+_R: BAT_HOLE+101.1, PSW101.2 (B)
COL0: R8.1, SW1.1, SW6.1, SW11.1, SW16.1, U2.1 (A4)
COL0_R: R105.1, SW101.1, SW106.1, SW111.1, SW116.1, U102.15 (A2)
COL1: R9.1, SW2.1, SW7.1, SW12.1, SW17.1, U2.2 (A6)
COL1_R: R106.1, SW102.1, SW107.1, SW112.1, SW117.1, U102.1 (A4)
COL2: R6.1, SW3.1, SW8.1, SW13.1, U2.15 (A2)
COL2_R: R108.1, SW103.1, SW108.1, SW113.1, U102.2 (A6)
COL3: R5.1, SW4.1, SW9.1, SW14.1, U2.14 (A1)
COL3_R: R109.1, SW104.1, SW109.1, SW114.1, U102.4 (A7)
COL4: R7.1, SW5.1, SW10.1, SW15.1, U2.12 (A3)
COL4_R: R107.1, SW105.1, SW110.1, SW115.1, U102.5 (A5)
CS: DISP1.5 (CS), U1.10 (7/E6)
CS_R: DISP101.5 (CS), U101.13 (B6/10)
DATA: J1.C, U1.1 (TX0/D3)
DATA_R: J101.C, U101.1 (TX0/D3)
GND: BAT_HOLE-1.1, C1.2, C2.2, C3.2, DISP1.4 (GND), J1.B, R5.2, R6.2, R7.2, R8.2, R9.2, R11.2, RSW1.2, SW1.3 (SG), SW2.3 (SG), SW3.3 (SG), SW4.3 (SG), SW5.3 (SG), SW6.3 (SG), SW7.3 (SG), SW8.3 (SG), SW9.3 (SG), SW10.3 (SG), SW11.3 (SG), SW12.3 (SG), SW13.3 (SG), SW14.3 (SG), SW15.3 (SG), SW16.3 (SG), SW17.3 (SG), U1.3 (GND), U1.4 (GND), U1.23 (GND), U2.4 (A7), U2.5 (A5), U2.7 (VEE), U2.8 (GND), U2.13 (A0), U3.4 (V-)
GND_R: BAT_HOLE-101.1, C101.2, C102.2, C103.2, DISP101.4 (GND), J101.B, R105.2, R106.2, R107.2, R108.2, R109.2, R111.2, R112.2, RSW101.2, SW101.3 (SG), SW102.3 (SG), SW103.3 (SG), SW104.3 (SG), SW105.3 (SG), SW106.3 (SG), SW107.3 (SG), SW108.3 (SG), SW109.3 (SG), SW110.3 (SG), SW111.3 (SG), SW112.3 (SG), SW113.3 (SG), SW114.3 (SG), SW115.3 (SG), SW116.3 (SG), SW117.3 (SG), U101.3 (GND), U101.4 (GND), U101.23 (GND), U102.7 (VEE), U102.8 (GND), U102.12 (A3), U102.13 (A0), U102.14 (A1), U103.4 (V-)
HAND: R12.1, U1.2 (RX1/D2)
HAND_R: R112.1, U101.2 (RX1/D2)
MOSI: DISP1.1 (MOSI), U1.5 (2/D1/SDA)
MOSI_R: DISP101.1 (MOSI), U101.5 (2/D1/SDA)
unnamed: JP1.1 (A), R10.1, R11.1, U3.2 (IN-)
unnamed: JP101.1 (A), R110.1, R111.1, U103.2 (IN-)
unnamed: R1.1, SW1.2, SW2.2, SW3.2, SW4.2, SW5.2
unnamed: R2.2, SW6.2, SW7.2, SW8.2, SW9.2, SW10.2
unnamed: R3.2, SW11.2, SW12.2, SW13.2, SW14.2, SW15.2
unnamed: R4.2, SW16.2, SW17.2
unnamed: R101.1, SW101.2, SW102.2, SW103.2, SW104.2, SW105.2
unnamed: R102.2, SW106.2, SW107.2, SW108.2, SW109.2, SW110.2
unnamed: R103.2, SW111.2, SW112.2, SW113.2, SW114.2, SW115.2
unnamed: R104.2, SW116.2, SW117.2
POWER: C1.1, C3.1, U1.16 (B1/15), U2.16 (VCC), U3.7 (V+)
POWER_R: C101.1, C103.1, U101.8 (5/C6), U102.16 (VCC), U103.7 (V+)
RAW: PSW1.3 (C), U1.24 (RAW)
RAW_R: PSW101.3 (C), U101.24 (RAW)
RESET: RSW1.1, U1.22 (RST)
RESET_R: RSW101.1, U101.22 (RST)
ROW0: R1.2, U1.7 (4/D4)
ROW0_R: R101.2, U101.20 (F4/A3)
ROW1: R2.1, U1.8 (5/C6)
ROW1_R: R102.1, U101.19 (F5/A2)
ROW2: R3.1, U1.9 (6/D7)
ROW2_R: R103.1, U101.17 (F7/A0)
ROW3: R4.1, U1.14 (B2/16)
ROW3_R: R104.1, U101.15 (B3/14)
SCK: DISP1.2 (SCK), U1.6 (3/D0/SCL)
SCK_R: DISP101.2 (SCK), U101.6 (3/D0/SCL)

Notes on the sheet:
Display
OpAmp
MUX
RESET
Matrix
TRRS
Battery
MCU

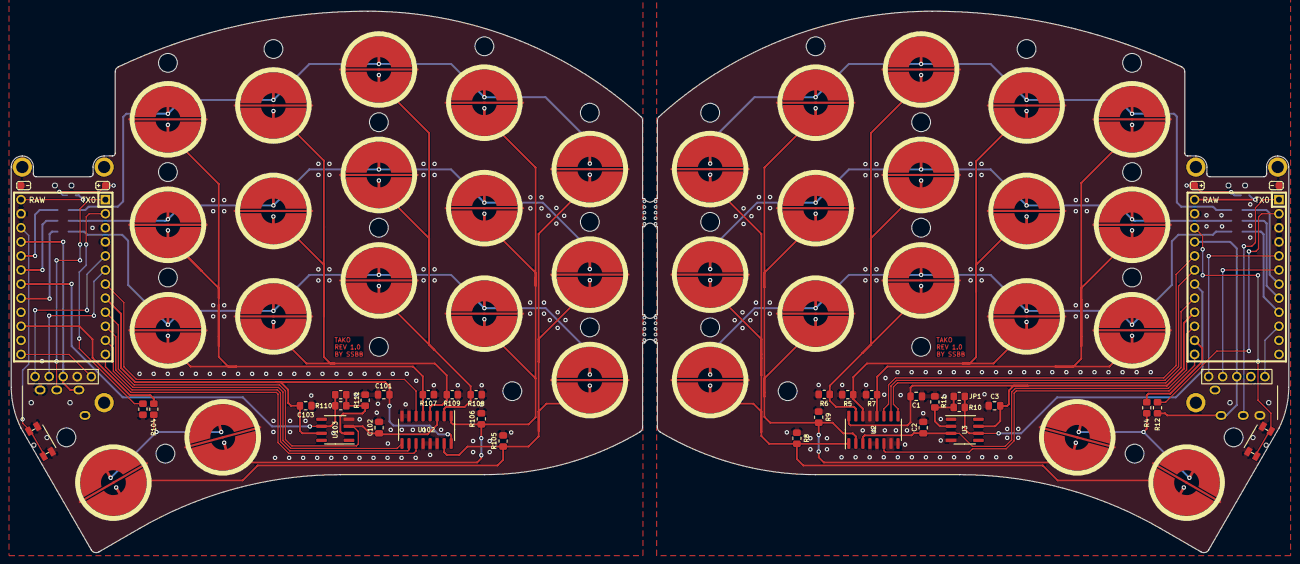
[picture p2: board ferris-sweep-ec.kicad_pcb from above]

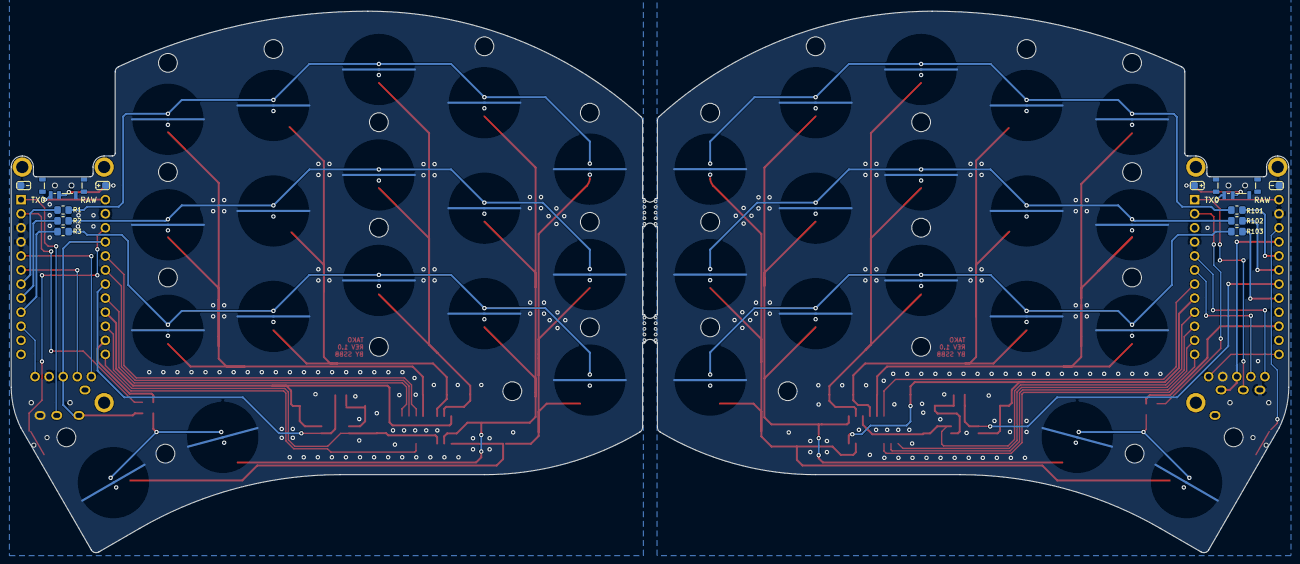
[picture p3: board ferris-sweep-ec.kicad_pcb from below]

Board: 2 copper layers, 230.7 x 97.8 mm, 120 parts (10 on the bottom side), 62 nets.

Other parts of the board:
mouse-bite-2mm-slot, mouse-bite-2mm-slot#2: VAL**; mouse-bite-5mm-slot-with-space-for-track

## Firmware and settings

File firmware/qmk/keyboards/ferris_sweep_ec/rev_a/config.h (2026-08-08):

/* Copyright 2023 ssbb
 *
 * This program is free software: you can redistribute it and/or modify
 * it under the terms of the GNU General Public License as published by
 * the Free Software Foundation, either version 2 of the License, or
 * (at your option) any later version.
 */

#pragma once

#define MATRIX_ROW_PINS \
    { D4, C6, D7, B2 }
#define MATRIX_ROW_PINS_RIGHT \
    { F4, F5, F7, B3 }

#define MATRIX_COL_CHANNELS \
    { 4, 6, 2, 1, 3 }
#define MATRIX_COL_CHANNELS_RIGHT \
    { 2, 4, 6, 7, 5 }

#define MUX_SEL_PINS \
    { F4, F5, F7 }
#define MUX_SEL_PINS_RIGHT \
    { B5, B4, E6 }

#define APLEX_EN_PIN B6
#define APLEX_EN_PIN_RIGHT D4

#define DISCHARGE_PIN B3
#define DISCHARGE_PIN_RIGHT D7

#define ANALOG_PORT F6

#define SPLIT_HAND_PIN D2
#define SERIAL_USART_TX_PIN D3

#define POWER_PIN B1
#define POWER_PIN_RIGHT C6

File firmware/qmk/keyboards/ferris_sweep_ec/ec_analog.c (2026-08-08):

/* Copyright 2023 ssbb
 *
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
 * You should have received a copy of the GNU General Public License
 * along with this program.  If not, see <http://www.gnu.org/licenses/>.
 */

#include "analog.h"
#include <ch.h>
#include <hal.h>

#if !HAL_USE_ADC
#    error "You need to set HAL_USE_ADC to TRUE in your halconf.h to use the ADC."
#endif

#if !RP_ADC_USE_ADC1 && !STM32_ADC_USE_ADC1 && !STM32_ADC_USE_ADC2 && !STM32_ADC_USE_ADC3 && !STM32_ADC_USE_ADC4 && !WB32_ADC_USE_ADC1
#    error "You need to set one of the 'xxx_ADC_USE_ADCx' settings to TRUE in your mcuconf.h to use the ADC."
#endif

#if STM32_ADC_DUAL_MODE
#    error "STM32 ADC Dual Mode is not supported at this time."
#endif

#if STM32_ADCV3_OVERSAMPLING
#    error "STM32 ADCV3 Oversampling is not supported at this time."
#endif

// Otherwise assume V3
#if defined(STM32F0XX) || defined(STM32L0XX)
#    define USE_ADCV1
#elif defined(STM32F1XX) || defined(STM32F2XX) || defined(STM32F4XX) || defined(GD32VF103) || defined(WB32F3G71xx) || defined(WB32FQ95xx)
#    define USE_ADCV2
#endif

// BODGE to make v2 look like v1,3 and 4
#if defined(USE_ADCV2) || defined(RP2040)
#    if !defined(ADC_SMPR_SMP_1P5) && defined(ADC_SAMPLE_3)
#        define ADC_SMPR_SMP_1P5 ADC_SAMPLE_3
#        define ADC_SMPR_SMP_7P5 ADC_SAMPLE_15
#        define ADC_SMPR_SMP_13P5 ADC_SAMPLE_28
#        define ADC_SMPR_SMP_28P5 ADC_SAMPLE_56
#        define ADC_SMPR_SMP_41P5 ADC_SAMPLE_84
#        define ADC_SMPR_SMP_55P5 ADC_SAMPLE_112
#        define ADC_SMPR_SMP_71P5 ADC_SAMPLE_144
#        define ADC_SMPR_SMP_239P5 ADC_SAMPLE_480
#    endif

#    if !defined(ADC_SMPR_SMP_1P5) && defined(ADC_SAMPLE_1P5)
#        define ADC_SMPR_SMP_1P5 ADC_SAMPLE_1P5
#        define ADC_SMPR_SMP_7P5 ADC_SAMPLE_7P5
#        define ADC_SMPR_SMP_13P5 ADC_SAMPLE_13P5
#        define ADC_SMPR_SMP_28P5 ADC_SAMPLE_28P5
#        define ADC_SMPR_SMP_41P5 ADC_SAMPLE_41P5
#        define ADC_SMPR_SMP_55P5 ADC_SAMPLE_55P5
#        define ADC_SMPR_SMP_71P5 ADC_SAMPLE_71P5
#        define ADC_SMPR_SMP_239P5 ADC_SAMPLE_239P5
#    endif

// we still sample at 12bit, but scale down to the requested bit range
#    define ADC_CFGR1_RES_12BIT 12
#    define ADC_CFGR1_RES_10BIT 10
#    define ADC_CFGR1_RES_8BIT 8
#    define ADC_CFGR1_RES_6BIT 6
#endif

/* User configurable ADC options */
#ifndef ADC_COUNT
#    if defined(RP2040) || defined(STM32F0XX) || defined(STM32F1XX) || defined(STM32F4XX) || defined(GD32VF103) || defined(WB32F3G71xx) || defined(WB32FQ95xx)
#        define ADC_COUNT 1
#    elif defined(STM32F3XX)
#        define ADC_COUNT 4
#    else
#        error "ADC_COUNT has not been set for this ARM microcontroller."
#    endif
#endif

#ifndef ADC_NUM_CHANNELS
#    define ADC_NUM_CHANNELS 1
#elif ADC_NUM_CHANNELS != 1
#    error "The ARM ADC implementation currently only supports reading one channel at a time."
#endif

#ifndef ADC_BUFFER_DEPTH
#    define ADC_BUFFER_DEPTH 1
#endif

// For more sampling rate options, look at hal_adc_lld.h in ChibiOS
#ifndef ADC_SAMPLING_RATE
#    define ADC_SAMPLING_RATE ADC_SMPR_SMP_1P5
#endif

// Options are 12, 10, 8, and 6 bit.
#ifndef ADC_RESOLUTION
#    ifdef ADC_CFGR_RES_10BITS // ADCv3, ADCv4
#        define ADC_RESOLUTION ADC_CFGR_RES_10BITS
#    else // ADCv1, ADCv5, or the bodge for ADCv2 above
#        define ADC_RESOLUTION ADC_CFGR1_RES_10BIT
#    endif
#endif

static ADCConfig   adcCfg = {};
static adcsample_t sampleBuffer[ADC_NUM_CHANNELS * ADC_BUFFER_DEPTH];

// Initialize to max number of ADCs, set to empty object to initialize all to false.
static bool adcInitialized[ADC_COUNT] = {};

// TODO: add back TR handling???
static ADCConversionGroup adcConversionGroup = {
    .circular     = FALSE,
    .num_channels = (uint16_t)(ADC_NUM_CHANNELS),
#if defined(USE_ADCV1)
    .cfgr1 = ADC_CFGR1_CONT | ADC_RESOLUTION,
    .smpr  = ADC_SAMPLING_RATE,
#elif defined(USE_ADCV2)
#    if !defined(STM32F1XX) && !defined(GD32VF103) && !defined(WB32F3G71xx) && !defined(WB32FQ95xx)
    .cr2   = ADC_CR2_SWSTART, // F103 seem very unhappy with, F401 seems very unhappy without...
#    endif
    .smpr2 = ADC_SMPR2_SMP_AN0(ADC_SAMPLING_RATE) | ADC_SMPR2_SMP_AN1(ADC_SAMPLING_RATE) | ADC_SMPR2_SMP_AN2(ADC_SAMPLING_RATE) | ADC_SMPR2_SMP_AN3(ADC_SAMPLING_RATE) | ADC_SMPR2_SMP_AN4(ADC_SAMPLING_RATE) | ADC_SMPR2_SMP_AN5(ADC_SAMPLING_RATE) | ADC_SMPR2_SMP_AN6(ADC_SAMPLING_RATE) | ADC_SMPR2_SMP_AN7(ADC_SAMPLING_RATE) | ADC_SMPR2_SMP_AN8(ADC_SAMPLING_RATE) | ADC_SMPR2_SMP_AN9(ADC_SAMPLING_RATE),
    .smpr1 = ADC_SMPR1_SMP_AN10(ADC_SAMPLING_RATE) | ADC_SMPR1_SMP_AN11(ADC_SAMPLING_RATE) | ADC_SMPR1_SMP_AN12(ADC_SAMPLING_RATE) | ADC_SMPR1_SMP_AN13(ADC_SAMPLING_RATE) | ADC_SMPR1_SMP_AN14(ADC_SAMPLING_RATE) | ADC_SMPR1_SMP_AN15(ADC_SAMPLING_RATE),
#elif defined(RP2040)
// RP2040 does not have any extra config here
#else
    .cfgr = ADC_CFGR_CONT | ADC_RESOLUTION,
    .smpr = {ADC_SMPR1_SMP_AN0(ADC_SAMPLING_RATE) | ADC_SMPR1_SMP_AN1(ADC_SAMPLING_RATE) | ADC_SMPR1_SMP_AN2(ADC_SAMPLING_RATE) | ADC_SMPR1_SMP_AN3(ADC_SAMPLING_RATE) | ADC_SMPR1_SMP_AN4(ADC_SAMPLING_RATE) | ADC_SMPR1_SMP_AN5(ADC_SAMPLING_RATE) | ADC_SMPR1_SMP_AN6(ADC_SAMPLING_RATE) | ADC_SMPR1_SMP_AN7(ADC_SAMPLING_RATE) | ADC_SMPR1_SMP_AN8(ADC_SAMPLING_RATE) | ADC_SMPR1_SMP_AN9(ADC_SAMPLING_RATE), ADC_SMPR2_SMP_AN10(ADC_SAMPLING_RATE) | ADC_SMPR2_SMP_AN11(ADC_SAMPLING_RATE) | ADC_SMPR2_SMP_AN12(ADC_SAMPLING_RATE) | ADC_SMPR2_SMP_AN13(ADC_SAMPLING_RATE) | ADC_SMPR2_SMP_AN14(ADC_SAMPLING_RATE) | ADC_SMPR2_SMP_AN15(ADC_SAMPLING_RATE) | ADC_SMPR2_SMP_AN16(ADC_SAMPLING_RATE) | ADC_SMPR2_SMP_AN17(ADC_SAMPLING_RATE) | ADC_SMPR2_SMP_AN18(ADC_SAMPLING_RATE)},
#endif
};
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

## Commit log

2026-08-08 Initial Ferris Sweep EC Revision A design
    [ferris-sweep-ec-bottom-plate.kicad_pcb, ferris-sweep-ec-topre-plate.kicad_pcb, ferris-sweep-ec.kicad_pcb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]
2026-08-08 Add wired JLCPCB production package
    [parts.csv]
